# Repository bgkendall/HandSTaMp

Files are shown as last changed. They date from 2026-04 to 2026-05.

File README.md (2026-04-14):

# HandSTaMp

## Bill of Materials

| Reference | Silkscreen | Part | Footprint | Purpose |
|---|---|---|---|---|
| C1, C2 | 1µF | 2 × 1µF ceramic capacitors  | 0603 | Decoupling capacitors for U3 |
| C3 | 4µ7F | 4.7µF ceramic capacitor | 0603 | Bulk decoupling capacitor for U1 |
| C4 | 100nF | 100nF ceramic capacitor | 0603 | Decoupling capacitor for U1 |
| C5 | 100nF | 100nF ceramic capacitor | 0603 | Unwanted reset prevention |
| D1 | D1 | PMEG2010EA Schottky diode | SOD-323 | Reverse current protection |
| D2, D3 | D2, D3 | 2 × 1N4148 diodes | SOD-123 | Matrix diodes for SW1/SW2 |
| F1 | F1 | 500mA fuse | 0603 | Current overload protection |
| J1 | J1 | HRO TYPE-C-31-M-12 USB port | | For the pluggings in of USB cables |
| R1, R2 | 1, 2 | 2 × 5.1kΩ resistors | 0603 | USB power negotiation (Rd) resistors |
| R3 | 5k1Ω – P | 5.1kΩ resistor | 0603 | OPTIONAL¹ 5V pull-up for RGB data line² |
| R4 | 1万Ω | 10kΩ resistor | 0603 | Prevention of unwanted boot state |
| S1, S2 | *None* | 2 × MX-compatible switches  | MX plate3³| Keys for row 0, columns 0/1; mountings for PCB |
| U1 | U1 | STM32C071GBU6 | UFQFPN-28 | ~~Braaaains!~~ Microcontroller |
| U2 | U2 | PRTR5V0U2X | SOT-143 | ESD protection |
| U3 | U3 | XC6206P332MR-G LDO | SOT-23-3  | 5V to 3.3V step-down for U1 |

##### Notes

 1. Remove/do not place R3 (“P”) if *not* using pin PB0 to drive RGB LEDs (e.g., as a regular matrix pin).
 2. When driving LEDs, pin PB0 must be set to [open drain mode][qmk-open-drain].
 3. Three-pin “plate-mount” switches can be used as-is. To use five-pin “PCB-mount” switches,
    the two extra plastic alignment “pins” must be removed.

[qmk-open-drain]: https://docs.qmk.fm/drivers/ws2812#open-drain-circuit

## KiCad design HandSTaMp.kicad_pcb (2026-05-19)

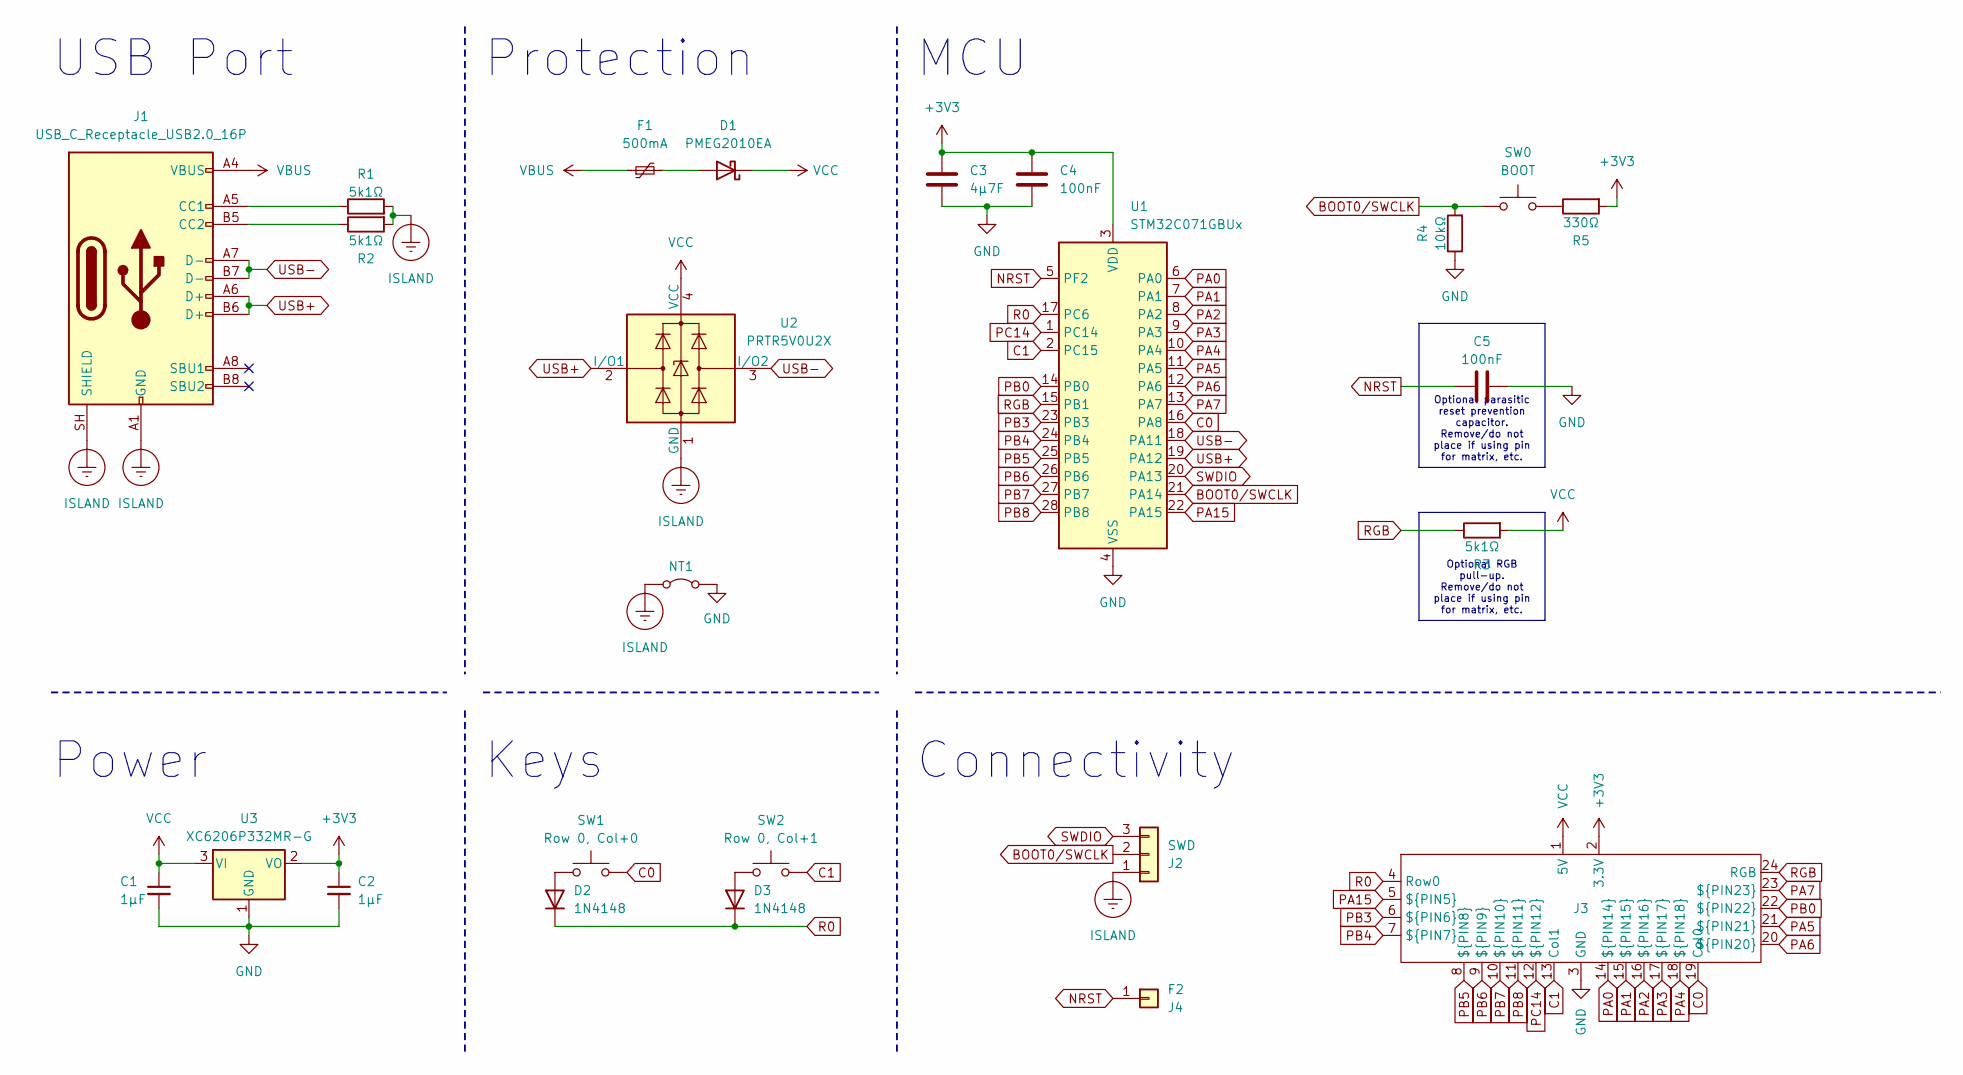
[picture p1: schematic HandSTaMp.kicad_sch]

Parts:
C1, C2: 1µF; C_0603_1608Metric; MPN CL10A105KO8NNNC; LCSC C1592
C3: 4µ7F; C_0603_1608Metric; MPN CL10A475KO8NNNC; DigiKey 1276-1784-1
C4, C5: 100nF; C_0603_1608Metric; MPN CL10B104KO8NNNC; DigiKey 1276-1005-1
D1: PMEG2010EA; D_SOD-323; MPN PMEG2010EA,115; LCSC C193668
D2, D3: 1N4148; D_SOD-123; MPN 1N4148W; DigiKey 1N4148WQ-7-FDI
F1: 500mA; Fuse_0603_1608Metric; MPN MF-FSMF050X-2; LCSC C210357
J1: USB_C_Receptacle_USB2.0_16P; USB_C_Receptacle_HRO_TYPE-C-31-M-12; MPN TYPE-C-31-M-12; DigiKey 2223-UJ20-C-H-G-SMT-1A-P16 (untested; m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
J2: SWD; SWD+GroundingPoint
J3: Pins; HandSTaMp
J4: F2; TestPoint_THTPad_D1.0mm_Drill0.5mm
NT1: Mounting Hole/Isolated Ground Jumper; NetTie-2_SMD_Pad0.5mm
R1, R2, R3: 5k1Ω; R_0603_1608Metric; MPN 0603WAF5101T5E/RC0603FR-075K1L; LCSC C23186
R4: 10kΩ; R_0603_1608Metric; MPN 0603WAF1002T5E/RC0603FR-0710KL; LCSC C25804
R5: 330Ω; R_0603_1608Metric; MPN 0603WAF3300T5E/RC0603FR-07330RL; LCSC C23138
SW0: BOOT; SW_SPST_B3U-1000P; MPN B3U-1000P; LCSC C231329
SW1: Row 0, Col+0; SW_MX_1u_PlateMount
SW2: Row 0, Col+1; SW_MX_1u_PlateMount
U1: STM32C071GBUx; QFN-28_4x4mm_P0.5mm; MPN STM32C071GBU6; DigiKey 497-STM32C071GBU6-ND
U2: PRTR5V0U2X; SOT-143; MPN PRTR5V0U2X,215; LCSC C12333
U3: XC6206P332MR-G; SOT-23-3; MPN XC6206P332MR-G; DigiKey 893-XC6206P332MR-G

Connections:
+3V3: C2.1, C3.1, C4.1, J3.2 (3.3V), R5.2, U1.3 (VDD), U3.2 (VO)
BOOT0/SWCLK: J2.2, R4.2, SW0.1, U1.21 (PA14)
C0: J3.19 (Col0), SW1.1, U1.16 (PA8)
C1: J3.13 (Col1), SW2.1, U1.2 (PC15)
GND: C1.2, C2.2, C3.2, C4.2, C5.2, J3.3 (GND), NT1.2 (B), R4.1, U1.4 (VSS), U3.1 (GND)
ISLAND: J1.A1 (GND), J1.A12 (GND), J1.B1 (GND), J1.B12 (GND), J1.SH (SHIELD), J2.1, NT1.1 (A), R1.2, R2.2, U2.1 (GND)
NRST: C5.1, J4.1 (Pin_1_1), U1.5 (PF2)
unnamed: D1.2 (A), F1.2
unnamed: D2.2 (A), SW1.2
unnamed: D3.2 (A), SW2.2
unnamed: J1.A5 (CC1), R1.1
unnamed: J1.B5 (CC2), R2.1
unnamed: R5.1, SW0.2
PA0: J3.14 (${PIN14}), U1.6 (PA0)
PA1: J3.15 (${PIN15}), U1.7 (PA1)
PA2: J3.16 (${PIN16}), U1.8 (PA2)
PA3: J3.17 (${PIN17}), U1.9 (PA3)
PA4: J3.18 (${PIN18}), U1.10 (PA4)
PA5: J3.21 (${PIN21}), U1.11 (PA5)
PA6: J3.20 (${PIN20}), U1.12 (PA6)
PA7: J3.23 (${PIN23}), U1.13 (PA7)
PA15: J3.5 (${PIN5}), U1.22 (PA15)
PB0: J3.22 (${PIN22}), U1.14 (PB0)
PB3: J3.6 (${PIN6}), U1.23 (PB3)
PB4: J3.7 (${PIN7}), U1.24 (PB4)
PB5: J3.8 (${PIN8}), U1.25 (PB5)
PB6: J3.9 (${PIN9}), U1.26 (PB6)
PB7: J3.10 (${PIN10}), U1.27 (PB7)
PB8: J3.11 (${PIN11}), U1.28 (PB8)
PC14: J3.12 (${PIN12}), U1.1 (PC14)
R0: D2.1 (K), D3.1 (K), J3.4 (Row0), U1.17 (PC6)
RGB: J3.24 (RGB), R3.1, U1.15 (PB1)
SWDIO: J2.3, U1.20 (PA13)
USB+: J1.A6 (D+), J1.B6 (D+), U1.19 (PA12), U2.2 (I/O1)
USB-: J1.A7 (D-), J1.B7 (D-), U1.18 (PA11), U2.3 (I/O2)
VBUS: F1.1, J1.A4 (VBUS), J1.A9 (VBUS), J1.B4 (VBUS), J1.B9 (VBUS)
VCC: C1.1, D1.1 (K), J3.1 (5V), R3.2, U2.4 (VCC), U3.3 (VI)

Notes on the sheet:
Keys
MCU
Connectivity
Protection
Power
USB Port
Optional RGB pull-up. Remove/do not place if using pin for matrix, etc.
Optional parasitic reset prevention capacitor. Remove/do not place if using pin for matrix, etc.

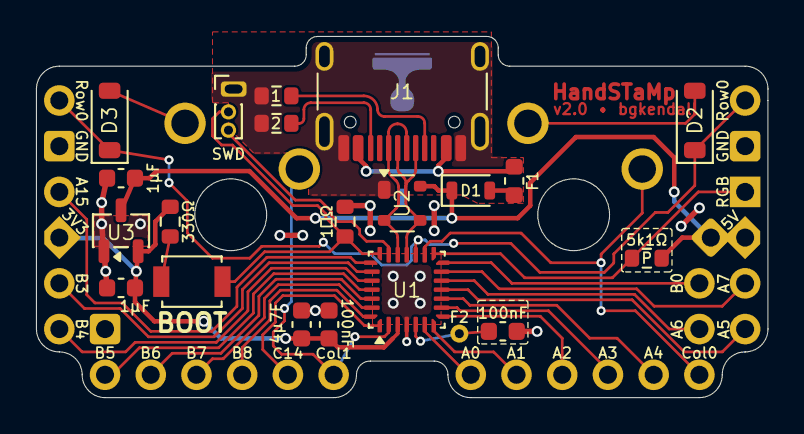
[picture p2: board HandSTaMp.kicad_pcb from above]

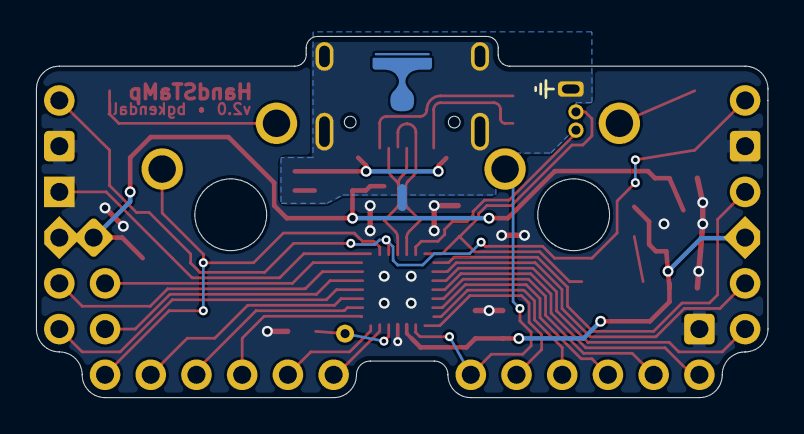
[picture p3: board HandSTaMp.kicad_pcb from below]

Board: 2 copper layers, 40.6 x 20.1 mm, 25 parts (3 on the bottom side), 37 nets.

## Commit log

2026-04-14 Tweak routing, especially R1 and C0
    [HandSTaMp.kicad_pcb, HandSTaMp.kicad_sch]
2026-04-14 Update constraints and fix various DRC errors
    The logo was getting a “copper slither” warning on the logo, so the handle and base shapes have been merged into one shape.
    The SWD pins have been spaced out a little.
    [HandSTaMp.kicad_pcb]
2026-04-24 Refine logo
    [HandSTaMp.kicad_pcb]
2026-04-24 Rework LDO area
    [HandSTaMp.kicad_pcb]
2026-04-24 Swap column pins to edge of group
    [HandSTaMp.kicad_pcb, HandSTaMp.kicad_sch]
2026-04-24 Move version/author label away from D2 silkscreen
    [HandSTaMp.kicad_pcb]
2026-04-24 Minor tweaks
    [HandSTaMp.kicad_pcb]
2026-04-25 Add LSCC, DigiKey and manufacturer’s part numbers
    BOM could be optimised to substitute some passive components with equivalent “Basic” parts if using JLC assembly.
    [HandSTaMp.kicad_pcb, HandSTaMp.kicad_sch]
2026-04-25 Move extra pin to short side
    This better avoids the switch as the left and right sides taper in a bit compared to the top and bottom sides, which are more straight.
    [HandSTaMp.kicad_pcb, HandSTaMp.kicad_sch]
2026-04-25 Add pad for PC15 access
    [HandSTaMp.kicad_pcb, HandSTaMp.kicad_sch]
2026-04-25 Move pad GPIO to THT connection
    * PC15 pad removed
    * Col1 switched to PC15
    * GND pin near right corner switched to GPIO
    * Bottom right pin assignments shuffled over one
    [HandSTaMp.kicad_pcb, HandSTaMp.kicad_sch]
2026-04-25 Update schematic presentation, check ERC and DRC
    Also, fix slight misalignment of external pins on PCB.
    [HandSTaMp.kicad_pcb, HandSTaMp.kicad_sch]
2026-04-27 Move items missing in previous change
    [HandSTaMp.kicad_pcb]
2026-04-27 Fix erroneously bold text
    [HandSTaMp.kicad_sch]
2026-05-19 Add access to PF2-NRST
    [HandSTaMp.kicad_pcb, HandSTaMp.kicad_sch]
2026-07-27 Update RGB pin note
    [HandSTaMp.kicad_sch]
